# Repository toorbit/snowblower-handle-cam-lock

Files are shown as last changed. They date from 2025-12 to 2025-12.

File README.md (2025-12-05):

# Snow Joe SJ625E Handle Cam Lock Replacement

**3D printable replacement parts for the Snow Joe SJ625E snowblower handle pivot joint.**

 

## 📥 Quick Start

**Just want to print?** Download the STL files from the [`stl/`](stl/) folder and load them into your slicer.

**On Printables:** [View on Printables.com](https://www.printables.com/) *(Link coming soon)*

---

## 📋 Table of Contents

- [Overview](#overview)
- [What You Need](#what-you-need)
- [Printing Guide](#printing-guide)
- [Assembly](#assembly)
- [Files Included](#files-included)
- [For Makers in Bend, OR](#for-makers-in-bend-or)
- [Customization](#customization)
- [Technical Specifications](#technical-specifications)
- [License & Credits](#license--credits)

---

## 🔍 Overview

This is a complete replacement for the broken handle cam lock (pivot joint) on the Snow Joe SJ625E electric snowblower. The original plastic part often fails, and Snow Joe's hardware kits typically don't include it.

**⚠️ Why This Design Exists:** According to forum reports, Snow Joe support has informed customers that this part is out of stock with no restocking planned, making it effectively discontinued. This 3D-printable replacement offers a permanent solution.

**Compatible Models:**
- Snow Joe SJ625E
- ION18SB series with similar handle assemblies

**OEM Part Reference:** ION18SB-9 (Part #8 in manual)  
**Official Manual:** [SJ625E Manual PDF](https://files.snowjoe.com/product-manuals/SJ625EMANUAL_ENG11082017-V1.pdf)  
**Support:** 1-866-SNOWJOE (1-866-766-9563)

---

## 🛠️ What You Need

### Parts to Print
- 1× Male cam lock (the rotating clamp)
- 1× Female cam lock (the fixed base)
- 1× Cam lever (the blue quick-release locking handle) - *Design coming soon*

**Note:** The cam lever design is not yet included but is planned for future release. It's the blue plastic lever that pivots on the bolt and locks the handle position via a camming action.

### Hardware (Not Included)
| Item | Specification | Where to Get |
|---|---|---|
| Pivot Bolt | M5 × 45-50mm with cross-hole in head | Hardware store (specialized) |
| Metal Pin | For cam lever attachment to bolt | Hardware store or Amazon |
| Compression Spring | 11mm OD / 9mm ID | Hardware store or Amazon |
| Handle Screw | M5 machine screw | Hardware store |
| Hex Nut | M5 hex nut (8.1mm width) | Hardware store |
| Washer | M5 washer (for pivot bolt) | Hardware store |
| Handle Tubes | 22mm OD tubing (upper & lower) | Original snowblower parts |

**Note:** The pivot bolt requires a horizontal cross-hole drilled through the head to accept the pin that connects the cam lever.

### Filament
- **Required:** PETG, ASA, or ABS (outdoor/cold rated)
- **DO NOT USE PLA** - will crack in freezing temperatures
- **Amount:** \~80-120g per part at full strength

---

## 🖨️ Printing Guide

### Orientation
- **Male Part:** Flat on bed, teeth pointing up
- **Female Part:** Flat on bed, largest circular face down

### Final Print Settings (Strong & Durable)

Use these settings for parts that will last:

| Setting | Value | Notes |
|---|---|---|
| **Material** | PETG, ASA, or ABS | Must be cold-resistant |
| **Layer Height** | 0.2mm | Good balance |
| **Walls** | 5 perimeters | ~2mm thick shell |
| **Infill** | 50-100% | Gyroid pattern recommended |
| **Top/Bottom** | 5 layers | Solid surfaces |
| **Supports** | Male: None / Female: Yes | Tree supports for female |
| **Brim** | 5-8mm | Prevents warping |

**Print Time:** \~4-6 hours per part  
**Material:** \~80-120g per part (\~$4-6 total)

### Test Print Settings (Fast & Cheap)

For initial fit-testing only:

| Setting | Value | Notes |
|---|---|---|
| **Layer Height** | 0.28-0.3mm | Faster |
| **Walls** | 3 perimeters | Minimum |
| **Infill** | 15-20% | Grid or Lightning |
| **Supports** | Tree supports | Uses less material |

**Print Time:** \~2-3 hours per part  
**Material:** \~30-40g per part (\~$1-2 total)

⚠️ **Test prints are for fit-checking only!** Once confirmed, print with final settings above.

---

## 🔧 Assembly

1. **Insert spring** into the groove on the male part's center hub
2. **Align teeth** - mesh the 40 teeth of both parts together
3. **Insert pivot bolt** through the center holes
4. **Slide handle tube** (22mm OD) into the sleeve
5. **Secure tube** with M5 screw and hex nut through screw boss
6. **Test rotation** - parts should lock in multiple positions

---

## 📦 Files Included

### STL Files (Ready to Print)
- [`stl/male-cam-lock.stl`](stl/male-cam-lock.stl) - Male rotating clamp
- [`stl/female-cam-lock.stl`](stl/female-cam-lock.stl) - Female fixed base

### Source Files (For Customization)
- `male-cam-lock.scad` - OpenSCAD parametric source
- `female-cam-lock.scad` - OpenSCAD parametric source

**Want to modify?** Install [OpenSCAD](https://openscad.org/) (free), edit the `.scad` files, and re-export.

---

## 📍 For Makers in Bend, OR

### DIYcave Makerspace
Print these parts locally at DIYcave!

- **Address:** 444 SE 9th Street, Bend, OR 97703
- **Phone:** (541) 388-2283
- **Web:** [diycave.com](https://www.diycave.com) | [Tool List](https://www.diycave.com/toollist)

**Hours:**
- Thu: 10am-10pm | Fri-Sat: 8am-8pm | Sun: 8am-5pm
- Mon-Wed: CLOSED (Private events only)

**3D Printers Available:**
- Creality Ender (220×220×250mm)
- Prusa i3 (250×210×210mm)

Both handle PETG/ASA/ABS. Your parts fit easily. Call ahead for rates and filament availability!

---

## 🎨 Customization

Both SCAD files are organized for easy modification:

```
// PRIMARY DIMENSIONS - Adjust these to customize
Body_OD = 70;           // Main body diameter
Tooth_Count = 40;       // Number of locking positions
Sleeve_Length = 50;     // Handle tube socket length

// CALCULATED DIMENSIONS - Auto-computed (don't edit)
// MODULES (female part) - Reusable geometry
```

**To customize:**
1. Open `.scad` file in OpenSCAD
2. Modify values in `PRIMARY DIMENSIONS` section
3. Press F5 to preview, F6 to render
4. Export as STL

---

## 📐 Technical Specifications

<details>
<summary><b>Click to expand detailed dimensions</b></summary>

### Male Part (Cam Lock / Tooth Hub)

| Feature | Measurement | Notes |
|---|---|---|
| Outer Diameter | 70mm | Main body |
| Body Height | 15mm | Outer rim |
| Hub Height | 18mm | Center hub |
| Tooth Count | 40 | Locking positions |
| Tooth Length | 6mm | Radial |
| Tooth Height | 3mm | Above rim |
| Tooth Width | 1.8mm | 3D print adjusted |
| Bolt Hole | 6mm | M5 clearance |
| Sleeve Length | 50mm | For 22mm tube |
| Socket ID | 23mm | 1mm tube clearance |

### Female Part (Base / Socket)

| Feature | Measurement | Notes |
|---|---|---|
| Outer Diameter | 70mm | Main body |
| Total Height | 24mm | Full part |
| Floor Height | 20mm | Solid interior |
| Tooth Count | 40 | Matches male |
| Tooth Gap | 2.5mm | 2mm teeth + 0.5mm clearance |
| Locking Box | 24×31mm | 2mm raised rim |

</details>

### Design Features

**Male Part:**
- Reinforced center hub with spring groove
- 40 teeth with stress-relief fillets for durability
- Rectangular sleeve for 22mm handle tube
- Screw boss with reinforcement gussets
- Side gussets for torsional strength

**Female Part:**
- 40 matching tooth slots with clearance
- 10mm deep locking pocket mechanism
- Spring retention sleeve
- Reinforced handle sleeve with cross braces
- Modular parametric design

---

## 📜 License & Credits

**Designer:** Theo Roe  
**Created:** December 2025  
**License:** [Creative Commons - Attribution (CC-BY)](https://creativecommons.org/licenses/by/4.0/)

Feel free to remix, modify, and share! Attribution appreciated.

---

## 🤝 Contributing

Found an issue or made an improvement? Contributions welcome!

- **Issues:** [GitHub Issues](https://github.com/toorbit/snowblower-handle-cam-lock/issues)
- **Improvements:** Submit a pull request or share your remix!
- **Printed successfully?** Share your make on Printables!

---

**Made with ❄️ for fellow snowblower owners**

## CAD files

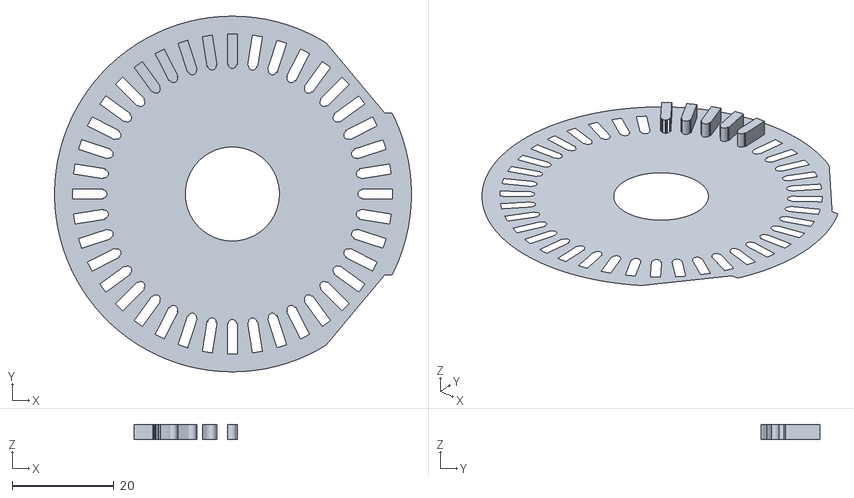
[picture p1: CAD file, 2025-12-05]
stl/male-cam-lock.stl
70.2 x 70.0 x 3.00

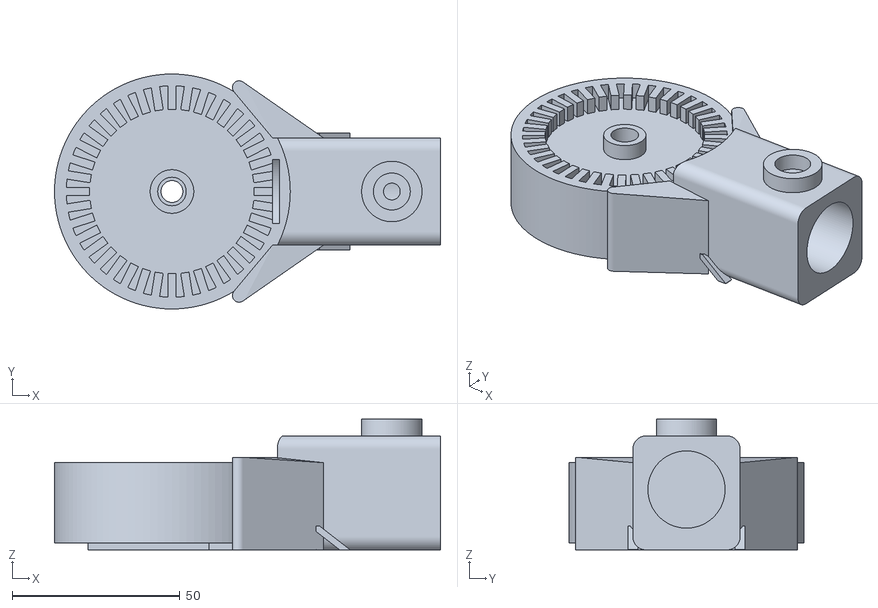
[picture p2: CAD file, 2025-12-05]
stl/female-cam-lock.stl
115.0 x 70.0 x 39.0

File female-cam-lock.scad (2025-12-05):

// =================================================================
// SNOW JOE HANDLE CAM LOCK REPLACEMENT - FEMALE PART (3D PRINTABLE)
// =================================================================
// Manufacturer: Snow Joe / Sun Joe
// Product: Ultra 21-Inch Electric Snow Thrower
// Model: SJ625E (Compatible with ION18SB series)
// Part Name: Handle Lock Base / Female Cam Lock / Pivot Joint Base
// OEM Part Number: ION18SB-9 (Mating part)
// Manual Reference: Part #8 (Handle locks) in SJ625E Exploded View
// Manual URL: https://files.snowjoe.com/product-manuals/SJ625EMANUAL_ENG11082017-V1.pdf
// 
// Designer: Theo Roe
// Date: December 5, 2025
// License: Creative Commons - Attribution (CC-BY)
// 
// SPECIFICATIONS:
// - Body: 70mm OD × 24mm H with 40 tooth slots
// - Floor Height: 20mm solid fill
// - Locking Box: 24mm × 31mm with 2mm raised edges
// - Hardware: M5 pivot bolt, 11mm OD compression spring
// 
// PRINT SETTINGS:
// - Material: PETG, ASA, or ABS (NOT PLA - cold/outdoor use)
// - Walls: Minimum 5 perimeters (2mm shell)
// - Infill: 40-100% (Gyroid recommended)
// - Supports: Required for horizontal sleeve and gussets
// - Orientation: Body flat on bed (largest face down)
// =================================================================

$fn = 100;

// ============================================================
// PRIMARY DIMENSIONS
// ============================================================

// Main body dimensions
Body_Height = 24;              // Total height of part
Body_OD = 70;                  // Outer diameter of body
Body_Fillet_Radius = 3;        // Fillet on outer edge
Body_Z_Offset = 2;             // Body raised above workplane for pocket flanges

Interior_Floor_Height = 19;    // Height of solid interior floor (gives 5mm teeth, 2mm clearance for 3mm male teeth)

// Tooth geometry (receives male part teeth)
Tooth_Count = 40;              // Number of teeth around circumference
Tooth_Width = 2.5;             // Width of each tooth
Tooth_Gap_Width = 2.5;         // Width of gap between teeth (2mm male teeth + 0.5mm clearance)
Teeth_Outer_Circle = 63;       // Diameter where teeth begin (matches male)
Tooth_Length = 7;              // How far teeth extend inward from rim

// Bolt and spring dimensions
Bolt_Hole_Diameter = 6;        // Diameter of center bolt
Bolt_Clearance = 0.5;          // Extra clearance for bolt
Bolt_Sleeve_OD = 13;           // OD of sleeve for spring (12mm spring + 1mm clearance)
Bolt_Sleeve_ID = 8.5;          // ID of sleeve (creates wall for 12mm OD spring to fit around)
// Spring specs: 12mm OD, 9mm ID, ~1.5mm wire gauge, 24mm total height (12mm per half)

// Locking mechanism pocket (receives locking tab)
Pocket_Width = 24;                // Pocket width (parallel to sleeve)
Pocket_Length = 31;               // Pocket length (perpendicular to sleeve)
// Pocket position set by its near-wall (the one closest to the bolt hole at X=0)
Pocket_Near_Wall_X = 9;           // Near wall of pocket cutout is 9mm from Bolt Hole (X=0)
Pocket_Start_X = Pocket_Near_Wall_X - Pocket_Width;   // Pocket Start X: 9mm - 24mm = -15mm
// **MODIFIED:** Definition for far flange extension
Pocket_Far_Extension = 10;        // How far the side flanges extend past the far pocket flange
Pocket_Flange_Width = 2;            // Width of raised flange around pocket
Pocket_Flange_Depth = 2;           // Depth of raised flange around pocket (sticks DOWN from body)

// Handle sleeve dimensions
Sleeve_Length = 50;            // Length of handle tube socket
Sleeve_Wall_Thick = 4.5;       // Wall thickness of sleeve
Sleeve_Corner_Rad = 4;         // Corner radius on sleeve
Sleeve_Tube_OD = 22;           // Handle tube outer diameter
Wiggle_Room = 1;               // Clearance for handle tube

// Screw boss dimensions (for handle securing screw, matches male part)
Screw_Hole_Dia = 5;            // Screw thread hole diameter
Screw_Hole_Margin = 12;        // Distance from end of sleeve
Screw_Head_Dia = 9;            // Screw head diameter
Boss_Wiggle = 2;               // Clearance around screw head
Boss_Wall_Thick = 3.5;         // Boss wall thickness
Boss_Height = 5;               // Boss height above sleeve

// Reinforcement dimensions
Gusset_Width = 15;             // Width of support gussets
Gusset_Height_Percent = 0.80;  // Gussets extend to 80% of sleeve height
Gusset_Outer_Fillet = 3;       // Fillet radius on gusset outer edge
Sleeve_Base_Thickening = 2;    // Extra wall thickness at sleeve base
Cross_Brace_Count = 3;         // Number of diagonal cross braces
Cross_Brace_Thickness = 3;     // Thickness of cross braces

// ============================================================
// CALCULATED DIMENSIONS
// ============================================================

// Tooth geometry
Teeth_Inner_Circle = Teeth_Outer_Circle - (2 * Tooth_Length);
Tooth_Height = Body_Height - Interior_Floor_Height;

// Pocket positioning
Pocket_Depth = 10;             // Fixed depth of pocket from bottom of body (excluding rim)

// Bolt positioning
Bolt_Center_X = 0;             // Centered on the main body
Bolt_Sleeve_Height = Tooth_Height;

// Screw boss
Boss_ID = Screw_Head_Dia + Boss_Wiggle;
Boss_OD = Boss_ID + (2 * Boss_Wall_Thick);
Screw_Hole_X = (30 + Sleeve_Length) - Screw_Hole_Margin - (Screw_Hole_Dia/2);

// Handle sleeve
Total_Hole_Dia = Sleeve_Tube_OD + Wiggle_Room;
Sleeve_Height = Total_Hole_Dia + (2 * Sleeve_Wall_Thick);
Sleeve_Width = Total_Hole_Dia + (2 * Sleeve_Wall_Thick);
Gusset_Actual_Height = Sleeve_Height * Gusset_Height_Percent;
Hole_Start_X = (Body_OD/2) + 10;

// ============================================================
// MODULES - Reusable Components
// ============================================================

module body_rim() {
    // Outer ring at full height, raised above workplane
    translate([0, 0, Body_Z_Offset])
    difference() {
        cylinder(d=Body_OD, h=Body_Height);
        // Hollow out center above interior floor
        translate([0, 0, Interior_Floor_Height])
            cylinder(d=Teeth_Outer_Circle, h=Tooth_Height + 1);
        // Outer edge fillet
        difference() {
            rotate_extrude() 
                translate([Body_OD/2, 0, 0]) 
                    square(Body_Fillet_Radius);
            rotate_extrude() 
                translate([Body_OD/2 - Body_Fillet_Radius, Body_Fillet_Radius, 0]) 
                    circle(r=Body_Fillet_Radius);
        }
    }
}

module interior_floor() {
    // Solid base inside teeth
    translate([0, 0, Body_Z_Offset])
    cylinder(d=Teeth_Inner_Circle, h=Interior_Floor_Height);
}

module teeth() {
    // Female teeth with gaps for male teeth to mesh
    translate([0, 0, Body_Z_Offset])
    for (i = [0 : Tooth_Count - 1]) {
        rotate([0, 0, i * (360 / Tooth_Count)]) {
            translate([
                0, 
                Teeth_Outer_Circle/2 - Tooth_Length/2, 
     
                Interior_Floor_Height + (Tooth_Height/2)
            ])
                cube([Tooth_Width, Tooth_Length, Tooth_Height], center=true);
        }
    }
}

module bolt_sleeve() {
    // Raised cylinder for spring to fit around
    translate([0, 0, Body_Z_Offset])
    difference() {
        translate([Bolt_Center_X, 0, Interior_Floor_Height]) // Uses Bolt_Center_X = 0
            cylinder(d=Bolt_Sleeve_OD, h=Bolt_Sleeve_Height);
        // Hollow center for spring
        translate([Bolt_Center_X, 0, Interior_Floor_Height - 1]) // Uses Bolt_Center_X = 0
            cylinder(d=Bolt_Sleeve_ID, h=Bolt_Sleeve_Height + 2);
    }
}

module pocket_flanges() {
    // **MODIFIED:** Calculate new ridge width and start position
    Pocket_Ridge_Width = Pocket_Width + Pocket_Far_Extension;
    Ridge_Start_X = Pocket_Start_X - Pocket_Far_Extension;
    
    // 3-sided raised flange frame around pocket (sits on workplane)
    
    // Left flange (Spans from Ridge_Start_X to Pocket_Near_Wall_X)
    translate([Ridge_Start_X, -(Pocket_Length/2) - Pocket_Flange_Width, 0])
        cube([Pocket_Ridge_Width, Pocket_Flange_Width, Pocket_Flange_Depth]);
    
    // Right flange (Spans from Ridge_Start_X to Pocket_Near_Wall_X)
    translate([Ridge_Start_X, (Pocket_Length/2), 0])
        cube([Pocket_Ridge_Width, Pocket_Flange_Width, Pocket_Flange_Depth]);
    
    // Near flange (Positioned at Pocket_Near_Wall_X)
    translate([Pocket_Near_Wall_X, -(Pocket_Length/2) - Pocket_Flange_Width, 0])
        cube([Pocket_Flange_Width, Pocket_Length + (2 * Pocket_Flange_Width), Pocket_Flange_Depth]);
}
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

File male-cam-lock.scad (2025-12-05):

// =================================================================
// SNOW JOE HANDLE CAM LOCK REPLACEMENT - MALE PART (3D PRINTABLE)
// =================================================================
// Manufacturer: Snow Joe / Sun Joe
// Product: Ultra 21-Inch Electric Snow Thrower
// Model: SJ625E (Compatible with ION18SB series)
// Part Name: Handle Lock / Handle Cam Lock / Pivot Joint
// OEM Part Number: ION18SB-9
// Manual Reference: Part #8 (Handle locks) in SJ625E Exploded View
// Manual URL: https://files.snowjoe.com/product-manuals/SJ625EMANUAL_ENG11082017-V1.pdf
// 
// Designer: Theo Roe
// Date: December 5, 2025
// License: Creative Commons - Attribution (CC-BY)
// 
// SPECIFICATIONS:
// - Body: 70mm OD × 15mm H with 40 locking teeth
// - Hub: 18.5mm OD × 18mm H with spring groove
// - Sleeve: 50mm L for 22mm handle tube with M5 retention screw
// - Hardware: M5 pivot bolt, 11mm OD compression spring
// 
// PRINT SETTINGS:
// - Material: PETG, ASA, or ABS (NOT PLA - cold/outdoor use)
// - Walls: Minimum 5 perimeters (2mm shell)
// - Infill: 40-100% (Gyroid recommended)
// - Supports: None required if printed flat
// - Orientation: Body flat on bed, teeth pointing up
// =================================================================

$fn = 100;

// ============================================================
// PRIMARY DIMENSIONS
// ============================================================

// Main body dimensions
Body_Height = 15;              // Total height of main disk
Body_OD = 70;                  // Outer diameter of body
Body_Fillet_Radius = 3;        // Fillet on outer edge

// Center hub dimensions
Center_Hub_Height = 18;        // Total height of center hub
Center_Hub_OD = 18.5;          // Outer diameter of center hub
Bolt_Hole_Diameter = 6;        // Diameter of center bolt

// Bottom counterbore (for bolt head)
Bottom_Counter_Dia = 10;       // Diameter of counterbore
Bottom_Counter_Dep = 10;       // Depth of counterbore

// Spring groove dimensions
Groove_Floor_Height = 6;       // Height where groove starts (allows 12mm spring depth)
Spring_Groove_OD = 12.5;       // Outer diameter of groove (12mm spring + 0.5mm clearance)
Spring_Groove_ID = 8.5;        // Inner diameter of groove (9mm spring ID - 0.5mm for center post)
// Spring specs: 12mm OD, 9mm ID, ~1.5mm wire gauge, 24mm total height (12mm per half)

// Tooth geometry (engages with female part)
Tooth_Count = 40;              // Number of teeth around circumference
Tooth_Length = 6;              // How far teeth extend outward from hub
Tooth_Width = 2.0;             // Width of each tooth
Teeth_Outer_Circle = 63;       // Diameter where teeth reach (matches female)
Tooth_Fillet_Radius = 0.8;     // Fillet at tooth base for stress relief

// Handle sleeve dimensions
Sleeve_Length = 50;            // Length of handle tube socket
Sleeve_Wall_Thick = 4.5;       // Wall thickness of sleeve
Sleeve_Corner_Rad = 4;         // Corner radius on sleeve
Sleeve_Tube_OD = 22;           // Handle tube outer diameter
Wiggle_Room = 1;               // Clearance for handle tube

// Screw boss dimensions (for handle securing screw)
Screw_Hole_Dia = 5;            // Screw thread hole diameter
Screw_Hole_Margin = 12;        // Distance from end of sleeve
Screw_Head_Dia = 9;            // Screw head diameter
Boss_Wiggle = 2;               // Clearance around screw head
Boss_Wall_Thick = 3.5;         // Boss wall thickness
Boss_Height = 5;               // Boss height above sleeve

// Reinforcement dimensions
Gusset_Width = 15;             // Width of support gussets
Gusset_Height_Percent = 0.80;  // Gussets extend to 80% of sleeve height
Gusset_Outer_Fillet = 3;       // Fillet radius on gusset outer edge

// ============================================================
// CALCULATED DIMENSIONS
// ============================================================

// Tooth geometry
Teeth_Inner_Circle = Teeth_Outer_Circle - (2 * Tooth_Length);
Tooth_Projection_Height = Center_Hub_Height - Body_Height;  // Height teeth project above body

// Screw boss
Boss_ID = Screw_Head_Dia + Boss_Wiggle;
Boss_OD = Boss_ID + (2 * Boss_Wall_Thick);
Screw_Hole_X = (30 + Sleeve_Length) - Screw_Hole_Margin - (Screw_Hole_Dia/2);

// Handle sleeve
Total_Hole_Dia = Sleeve_Tube_OD + Wiggle_Room;
Sleeve_Height = Total_Hole_Dia + (2 * Sleeve_Wall_Thick);
Sleeve_Width = Total_Hole_Dia + (2 * Sleeve_Wall_Thick);
Gusset_Actual_Height = Sleeve_Height * Gusset_Height_Percent;
Hole_Start_X = (Body_OD/2) + 10;

// ============================================================
// MAIN GEOMETRY
// ============================================================

// ============================================================
// MAIN ASSEMBLY
// ============================================================

difference() {
    
    // POSITIVE GEOMETRY
    union() {
        
        // ====================================================
        // BODY WITH TEETH
        // ====================================================
        difference() {
            union() {
                // Main body disk
                cylinder(d=Body_OD, h=Body_Height);
                
                // Center hub
                translate([0,0,0]) 
                    cylinder(d=Center_Hub_OD, h=Center_Hub_Height);
                
                // Teeth with base fillets for stress relief
                for (i = [0 : Tooth_Count - 1]) {
                    rotate([0, 0, i * (360 / Tooth_Count)]) { 
                        // Main tooth body
                        translate([0, (Teeth_Outer_Circle/2) - (Tooth_Length/2), Body_Height + (Tooth_Projection_Height/2)])
                            cube([Tooth_Width, Tooth_Length, Tooth_Projection_Height], center=true);
                        
                        // Fillet at tooth base for stress relief
                        translate([0, (Teeth_Inner_Circle/2), Body_Height])
                            cylinder(r=Tooth_Fillet_Radius, h=Tooth_Projection_Height);
                    }
                }
            } 
            
            // Body outer fillet
            difference() {
                rotate_extrude() 
                    translate([Body_OD/2, 0, 0]) 
                        square(Body_Fillet_Radius); 
                rotate_extrude() 
                    translate([Body_OD/2 - Body_Fillet_Radius, Body_Fillet_Radius, 0]) 
                        circle(r=Body_Fillet_Radius); 
            }
        } 

        // ====================================================
        // SLEEVE
        // ====================================================
        difference() {
            translate([30, 0, 0]) 
                rotate([0, 0, 0])
                rotate([90, 0, 90]) 
                linear_extrude(Sleeve_Length)
                    hull() {
                        translate([-(Sleeve_Width/2) + Sleeve_Corner_Rad, Sleeve_Corner_Rad]) 
                            circle(r=Sleeve_Corner_Rad);
                        translate([(Sleeve_Width/2) - Sleeve_Corner_Rad, Sleeve_Corner_Rad]) 
                            circle(r=Sleeve_Corner_Rad);
                        translate([-(Sleeve_Width/2) + Sleeve_Corner_Rad, Sleeve_Height - Sleeve_Corner_Rad]) 
                            circle(r=Sleeve_Corner_Rad);
                        translate([(Sleeve_Width/2) - Sleeve_Corner_Rad, Sleeve_Height - Sleeve_Corner_Rad]) 
                            circle(r=Sleeve_Corner_Rad);
                    }
            
            // Concave clearance cut
            translate([0,0, Body_Height])
                cylinder(d=Body_OD + 0.5, h=Sleeve_Height);
            
            // Embossed text on sleeve (indented 0.5mm)
            translate([55, 0, Sleeve_Height - 3])
                rotate([90, 0, 90])
                linear_extrude(height = 0.5)
                    text("SJ625E", size=4, halign="center", valign="center", font="Liberation Sans:style=Bold");
        }
        
        // ====================================================
        // SCREW BOSS WITH REINFORCEMENT
        // ====================================================
        translate([Screw_Hole_X, 0, Sleeve_Height - 2.0])
             cylinder(d=Boss_OD, h=Boss_Height + 2); 

        // Boss reinforcement gusset
        hull() {
            translate([Screw_Hole_X, 0, Sleeve_Height - 2.0])
                cylinder(d=Boss_OD, h=0.5);
            translate([Screw_Hole_X - 8, 0, Sleeve_Height/2])
                cylinder(d=4, h=0.5);
        }
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

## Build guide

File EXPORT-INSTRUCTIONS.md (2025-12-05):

# How to Export STL Files

Since OpenSCAD command-line export isn't working properly, follow these steps:

## Manual Export Steps

### Male Part:
1. Open OpenSCAD (located at: `C:\Program Files\OpenSCAD\openscad.exe`)
2. File → Open → Select `male-cam-lock.scad`
3. Press **F6** (or Design → Render) - This will take 1-2 minutes
4. Wait for rendering to complete (watch bottom status bar)
5. File → Export → Export as STL
6. Save as: `stl\male-cam-lock.stl`

### Female Part:
1. File → Open → Select `female-cam-lock.scad`
2. Press **F6** (or Design → Render) - This will take 1-2 minutes  
3. Wait for rendering to complete
4. File → Export → Export as STL
5. Save as: `stl\female-cam-lock.stl`

## Verify Files Created:
```powershell
Get-ChildItem stl\
```

You should see:
- `male-cam-lock.stl` (~200-500 KB)
- `female-cam-lock.stl` (~400-800 KB)

## Then Commit to Git:
```powershell
git add stl/*.stl
git add .gitignore
git add README.md
git commit -m "Add STL files for 3D printing and update documentation"
git push
```

Delete this file after export is complete.

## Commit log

2025-12-05 Initial commit: Snow Joe SJ625E handle cam lock replacement parts
    [female-cam-lock.scad, male-cam-lock.scad]
2025-12-05 Integrated the detailed specifications from my research.
    [female-cam-lock.scad, male-cam-lock.scad]
2025-12-05 Add STL files and update documentation for Printables
    [female-cam-lock.stl, male-cam-lock.stl]
2025-12-05 Updated handle tube parts

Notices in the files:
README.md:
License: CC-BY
